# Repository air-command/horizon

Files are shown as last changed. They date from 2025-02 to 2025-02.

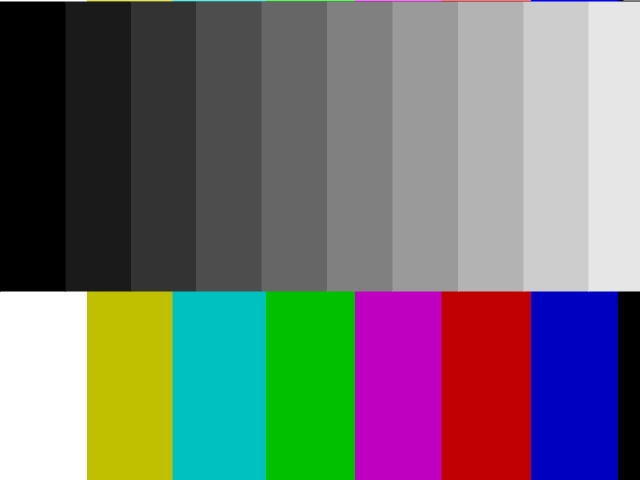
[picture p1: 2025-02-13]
01_Launcher/A5_Controller/rpi_190308/test.jpg

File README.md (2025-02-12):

# Horizon - 2 Stage Water Rocket
## Introduction
The files available in this repository are free of charge, but we would appreciate credit if you use these files in your projects. 
The files are provided as-is in the hope some may be used as a reference when working on your own projects. 

This is not a step-by-step guide how to build the Horizon rocket.
This repository is not an exhaustive breakdown of all the components in the Horizon project, it is simply a collection of files that we had used during the construction of the project.

## Navigating the data set
Components use Unit number / Assembly Number / Part Number labeling scheme.

Example: 03A2A3P6 expands to 03_Booster > A2_Deployment > A3_Camera_Pod > P6_Battery_808
Which refers to the 808 camera battery mount of the camera pod on top of the Booster. 

The **info.txt** files in any folder include general information about that assembly or part. 

## PLEASE NOTE
This repository will be actively updated over the coming weeks/months as we organize all the files.

## Construction Videos
The YouTube playlist with all the construction videos is available here:\
https://www.youtube.com/playlist?list=PL-zcDPSotX7pQ490T-lMMBW_i7fbfD8UH

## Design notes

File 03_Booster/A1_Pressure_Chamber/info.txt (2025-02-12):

Booster test pressure chamber
Inner liner + booster spacing jig cylinders: 85 gsm cloth single wrap -1060x290mm - Needed 2 pumps

2 layers of 200gsm carbon fiber - 5 pumps including peel ply. 

3" light sleeve over top for spacing jig cylinders. 

1 - pump for internal coat of pressure chamber.

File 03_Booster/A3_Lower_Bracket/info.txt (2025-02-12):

The lower bracket joins the booster segments together at the bottom of the booster. There are 3 of them. 
The bracket is glued to the bracket pads with 24hour Araldite, and then reinforced - See P3

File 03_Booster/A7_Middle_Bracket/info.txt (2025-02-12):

The middle bracket holds the 3 booster segments together, and supports the staging mechanism. The entire booster is held down by the middle bracket.

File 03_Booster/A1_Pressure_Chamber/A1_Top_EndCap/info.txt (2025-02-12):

--------------
Top Endcap

210mm long 2.5" medium carbon sleeve.
4 x 85 gsm fiberglass plain weave gores
1 x 40mm wide single wrap of 85 gsm fiberglass for the base.

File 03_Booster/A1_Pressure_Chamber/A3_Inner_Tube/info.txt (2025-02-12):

P2 - 85gsm fiberglass single wrap - applied as 2 separate pieces, overlapped in the middle. 
P3 - 200gsm carbon fiber plain weave = 2 wraps - single piece
P4 - peel ply on the outside. - applied as 2 separate pieces, overlapped in the middle. 

- thin masking tape 
- baking paper - split in half, 4.8m long - each half can make 1 tube. 
- west systems epoxy 3-4 pumps for fiberglass inner liner
- west systems epoxy 10-12 pumps for carbon wrap including peel ply. 

After curing and removing from mandrel. 
- inside is coated 2x with west systems - 3 pumps per coat. 

NOTE: DO NOT EXTEND TAPE into the joint between endcaps.

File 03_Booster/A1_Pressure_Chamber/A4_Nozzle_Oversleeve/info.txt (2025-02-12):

This nozzle oversleve is made from 42mm aluminium bar. It is a fix for the nozzle leak.

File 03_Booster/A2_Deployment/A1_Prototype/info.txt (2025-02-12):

This was a prototype flown on Horizon Part #33

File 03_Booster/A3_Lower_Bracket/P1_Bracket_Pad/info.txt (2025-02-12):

The bracket pad attaches the bracket to the pressure chamber. It is made from a curved section made from carbon fiber. 
Several of these curved sections are made from a larger tube. This tube is made from 850x270mm 200gsm carbon fiber plain weave cloth. This is 3 wraps over a pressure chamber mandrel. Note that the mandrel for this is the actual pressure chamber, rather than the mandrel used to make the pressure chamber. This carbon fiber tube is topped with 1 wrap of 85gsm 300x270mm plain weave fiberglass for a nicer finish. It took 2 pumps to fully wet out.

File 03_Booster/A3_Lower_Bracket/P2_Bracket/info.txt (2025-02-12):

The bracket joins the two bracket pads together. It is made from 3mm CF plate from Hobby King. 
Each bracket is made from 60x130mm rectangle.

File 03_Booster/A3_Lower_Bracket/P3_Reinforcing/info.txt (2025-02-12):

After the bracket is glued to the bracket pads with 24hour Araldite, each joint is reinforced from the outside with 10 layers of 85gsm fiberglass cloth. Each layer alternates in orientation 0-90 and 45-45.

Here are the layers cut out from the FG cloth:
45x60 x3
40x60 x3
35x60 x2
30x60 x2

The inside corner is reinforced with 6 alternating 0-90 and 45-45 layers of 85gsm cloth all the same size 60x35mm

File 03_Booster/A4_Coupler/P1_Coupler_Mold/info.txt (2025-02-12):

5 layers top and bottom
3 perimeter layers
10% infill
0.25mm layer height 
PLA
default printing speed: 4800mm/min

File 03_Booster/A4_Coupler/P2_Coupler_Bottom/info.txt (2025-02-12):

The top and bottom couplers are made together in one piece and then cut. 
1mm wall thickness.
3 wraps of 200gsm plain weave CF 770 x 70mm
3 wraps of 85gsm plain weave Fiberglass 700 x 70mm
Uses 1 pump of epoxy
Bottom coupler is 40mm tall
Top coupler is 25mm tall.

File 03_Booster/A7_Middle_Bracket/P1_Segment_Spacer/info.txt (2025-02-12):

The segment spacer helps align the middle brackets during construction. The spacer also is used during the assembly of the entire booster to get the correct inter-segment spacing. 

3D Printer settings:

5 layers top and bottom
3 perimeter layers
10% infill
0.25mm layer height 
PLA
default printing speed: 3000mm/min

3 hours to print

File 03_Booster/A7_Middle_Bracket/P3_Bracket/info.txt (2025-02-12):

There are 6 brackets made from 3mm carbon fiber plate. Each bracket is 50mm wide, 140mm long on the outside and 110mm on the inside.

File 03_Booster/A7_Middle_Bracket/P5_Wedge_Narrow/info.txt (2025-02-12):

This is used to help force the reinforcing cloth into shape in the narrow spaces between the brackets.

PLA+ Black
3 top and bottom layers
0.25 layer height
speed 4800
3 perimeter layers
10% infill

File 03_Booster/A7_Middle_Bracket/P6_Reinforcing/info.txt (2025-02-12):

Narrow wedge reinforcing:
layer 1: 0-90 200gsm Carbon fiber 45 x 130mm
layer 2: 45-45 200gsm Carbon fiber 45 x 130mm
layer 3: 0-90 200gsm Carbon fiber 45 x 130mm
layer 4: 45-45 200gsm Carbon fiber 45 x 130mm
top layer: 0-90 85gsm fiberlgass 45 x 130mm
baking paper on top and pressed down with the 3D printed Wedge
This is repeated 3 times

Wide wedge reinforcing:
layer 1: 0-90 200gsm Carbon fiber 50 x 130mm
layer 2: 45-45 200gsm Carbon fiber 50 x 130mm
layer 3: 0-90 200gsm Carbon fiber 50 x 130mm
layer 4: 45-45 200gsm Carbon fiber 50 x 130mm
top layer: 0-90 85gsm fiberlgass 50 x 130mm
baking paper on top and pressed down with the 3D printed Wedge
This is repeated 3 times

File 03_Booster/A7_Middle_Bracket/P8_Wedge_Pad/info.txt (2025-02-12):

This is used to help force the reinforcing cloth into shape between the bracket and the curved pad

PLA+ White
3 top and bottom layers
0.25 layer height
speed 4800
3 perimeter layers
10% infill

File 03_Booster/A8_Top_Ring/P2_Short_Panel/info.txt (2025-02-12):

The top ring is made from 3 short and 3 long panels. 
The short panel is 136mm x 67mm
The long panel is 147mm x 67mm
Each panel's edges are angled where they meet together.

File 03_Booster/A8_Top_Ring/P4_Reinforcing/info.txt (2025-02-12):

The reinforcing on the outside and inside of each joint of the ring is the same. 
The following layers are used. The shortest is on the inside and the longest is on the outside.

layer 1: 20 x 80mm - 45-45 CF
layer 2: 30 x 80mm - 0-90 CF
layer 3: 30 x 80mm - 45-45 CF
layer 4: 40 x 80mm - 0-90 CF
layer 5: 50 x 80mm - 45-45 CF
layer 6: 55 x 80mm - 0-90 85 gsm glass

These are all layed up on a piece of baking paper with the outside first
These are then applied to both the inside and outside and compressed together between the P1_Wedges until cured.

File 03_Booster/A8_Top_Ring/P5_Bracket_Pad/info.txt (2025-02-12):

This is a pad that attaches the top ring to the booster segment. It is made from a tube whose inside diameter is the outside diameter of the booster segment. The pad itself is 77mm long and 55mm wide.

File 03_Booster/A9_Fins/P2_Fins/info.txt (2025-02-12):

The fins are made from 3mm plywood.
Each side has:
Lowest level: 
bias cut 200gsm glass
straight cut CF sheet
bias cut CF sheet
straight cut 85gsm glass. 

Size of plywood was 23cm x 36cm
Size of cloth: 24cm x 36cm

Each side took 2 pumps of epoxy

Fins were sandwitched between two plates of glass.

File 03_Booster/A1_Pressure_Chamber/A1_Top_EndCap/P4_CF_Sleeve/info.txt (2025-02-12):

210mm long 2.5" Medium Carbon fiber sleeve

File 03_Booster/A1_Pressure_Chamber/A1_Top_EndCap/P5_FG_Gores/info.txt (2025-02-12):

4 x 85gsm plain weave fiberglass, bias cut - shape based on template.

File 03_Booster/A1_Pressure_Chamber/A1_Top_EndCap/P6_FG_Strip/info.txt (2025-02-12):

2 wraps of 40mm wide 85gsm fiberglass cloth. 
This is wrapped around the base after the gores have been applied to the sleeve.

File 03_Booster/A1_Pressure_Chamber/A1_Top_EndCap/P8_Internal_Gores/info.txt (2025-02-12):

21 x 85gsm gores applied to the inside of the endcap. The pattern is straight cut (not bias) using the cardboard pattern. 
The gores are applied in 3 layers with 7 gores per layer. Each layer is offset by 1/3 the width of a gore.

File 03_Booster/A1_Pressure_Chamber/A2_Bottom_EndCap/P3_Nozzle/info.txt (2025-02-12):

Nozzle is machined from aluminium.
Internal diameter: 19.45mm
Extternal diameter: 22.75mm
Length: 25mm

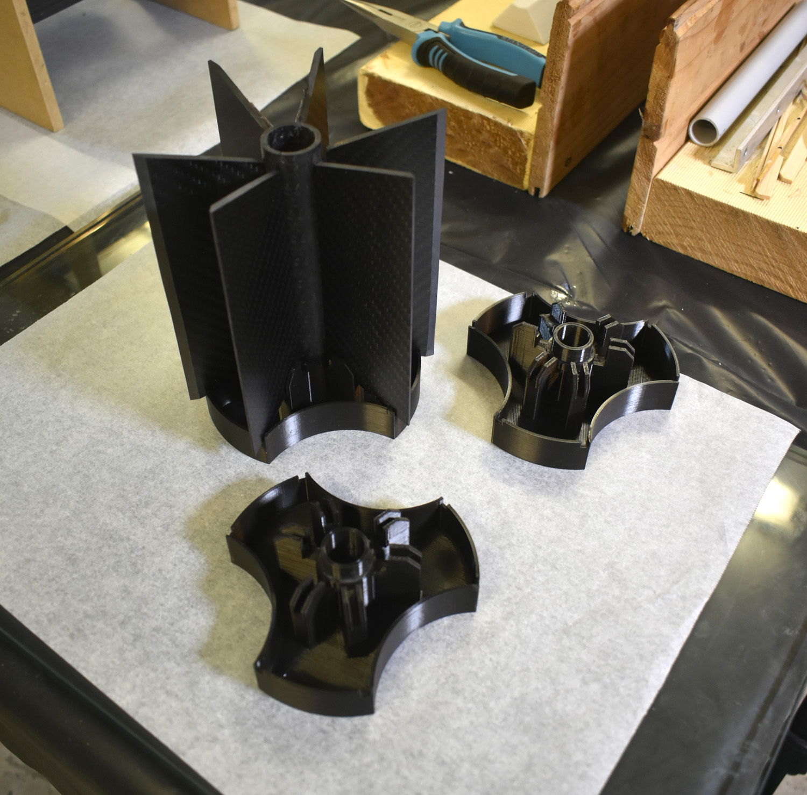
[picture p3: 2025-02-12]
03_Booster/A7_Middle_Bracket/photos/A7_Bracket2.jpg

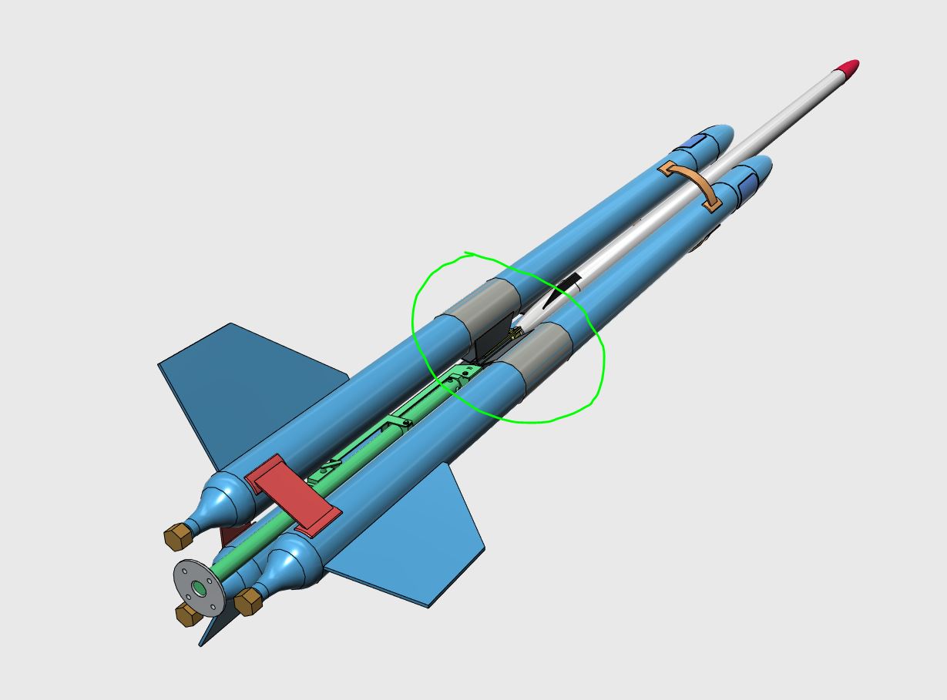
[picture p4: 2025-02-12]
03_Booster/A7_Middle_Bracket/photos/middle_bracket.JPG

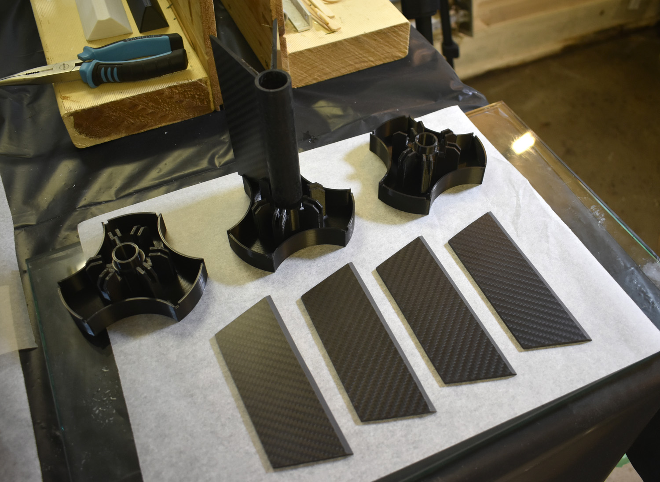
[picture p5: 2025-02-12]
03_Booster/A7_Middle_Bracket/photos/A7_Bracket1.jpg

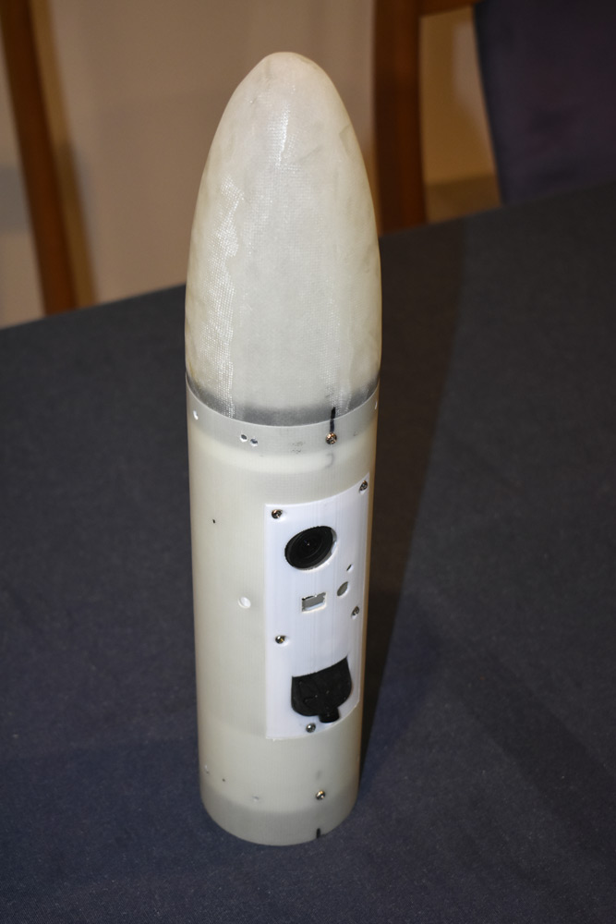
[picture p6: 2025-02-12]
03_Booster/A2_Deployment/A2_Main_Deploy/photos/CameraPod1.jpg

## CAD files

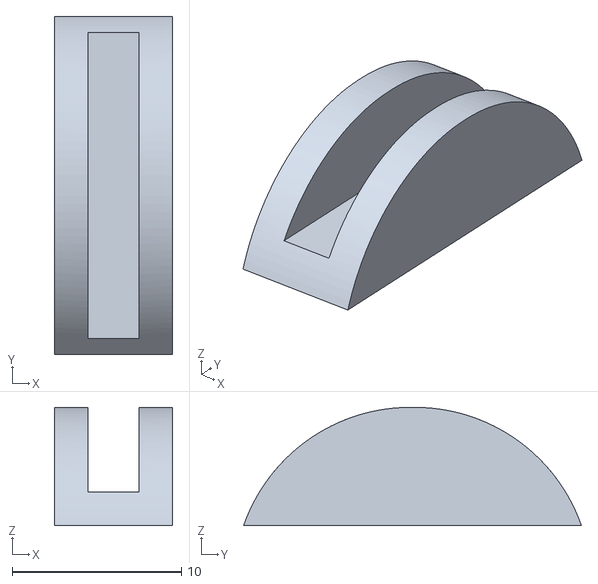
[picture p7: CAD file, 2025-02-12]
03_Booster/A10_ParachuteHarness/P1_ShockCord_Mount.stl
7.00 x 20.0 x 7.00

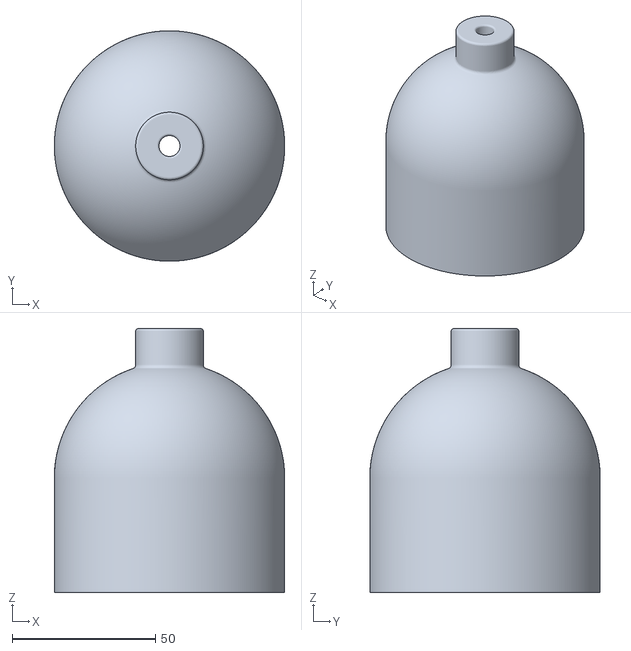
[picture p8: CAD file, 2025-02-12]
03_Booster/A1_Pressure_Chamber/A1_Top_EndCap/P1_Top_EndCap_Mold/P1_Top_EndCap_Mold_2.stl
80.4 x 80.4 x 92.1

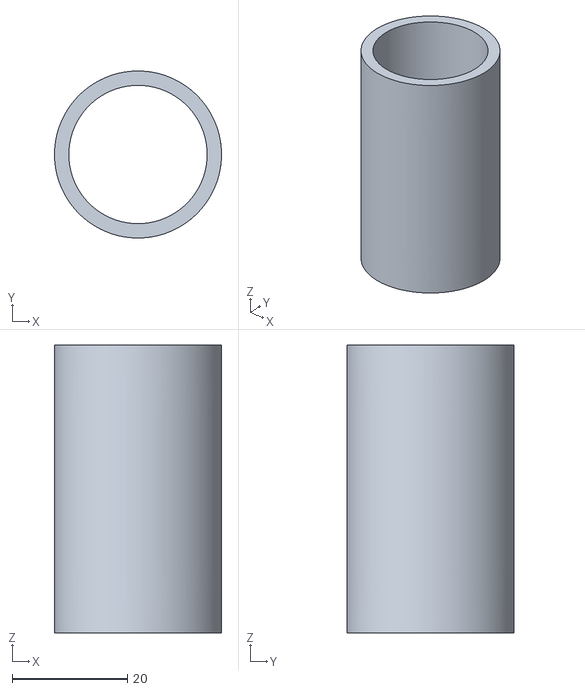
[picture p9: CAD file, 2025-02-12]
03_Booster/A1_Pressure_Chamber/A1_Top_EndCap/P2_Top_EndCap_Ring/P2_Top_EndCap_Ring.stl
29.0 x 29.0 x 50.0

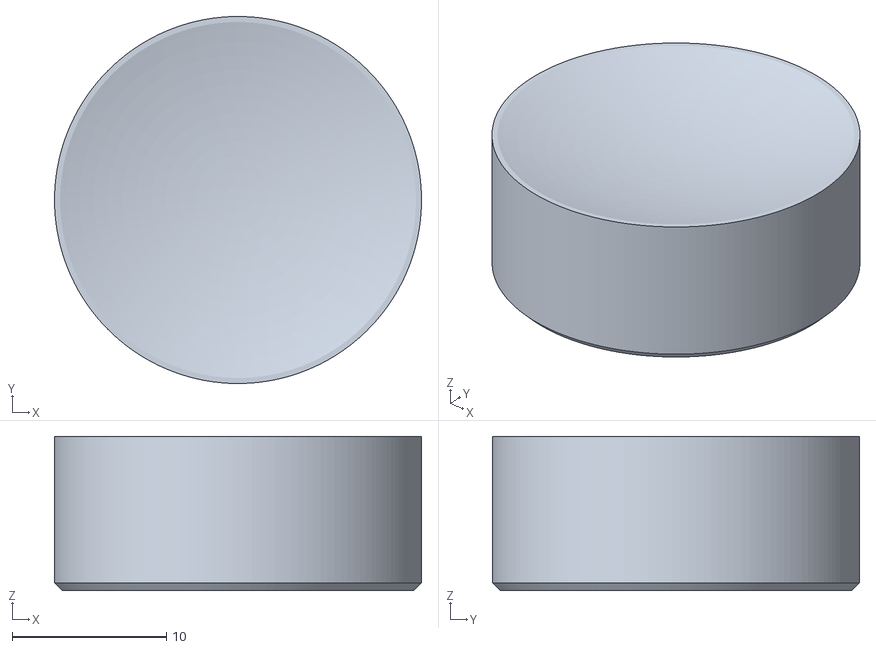
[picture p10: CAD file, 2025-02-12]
03_Booster/A1_Pressure_Chamber/A1_Top_EndCap/P3_Top_EndCap_Plug/P3_Top_EndCap_Plug.stl
23.8 x 23.8 x 10.0

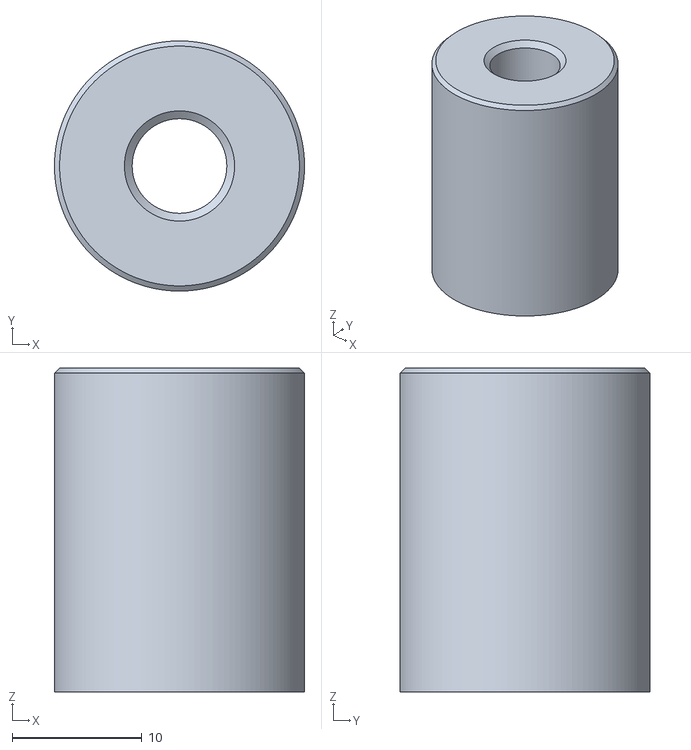
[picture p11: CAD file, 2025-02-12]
03_Booster/A1_Pressure_Chamber/A2_Bottom_EndCap/P1_NozzleMeasure/P1_NozzleMeasure.stl
19.3 x 19.3 x 25.0

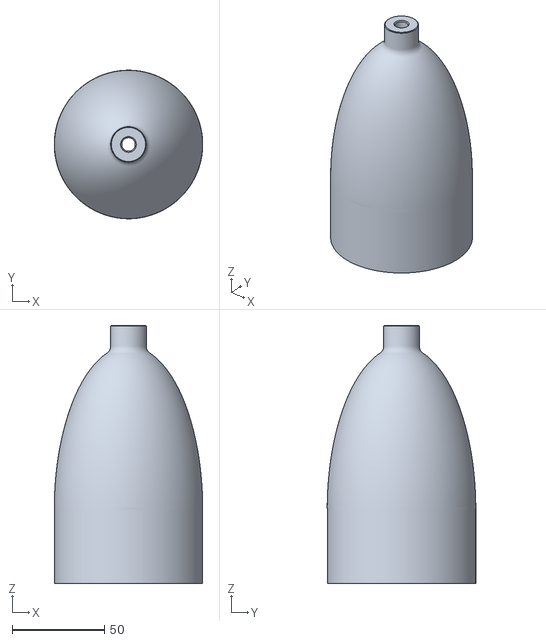
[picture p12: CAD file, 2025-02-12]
03_Booster/A1_Pressure_Chamber/A2_Bottom_EndCap/P2_Bottom_Endcap_Mold/P2_Bottom_Endcap_Mold_2.stl
80.4 x 80.5 x 139.7

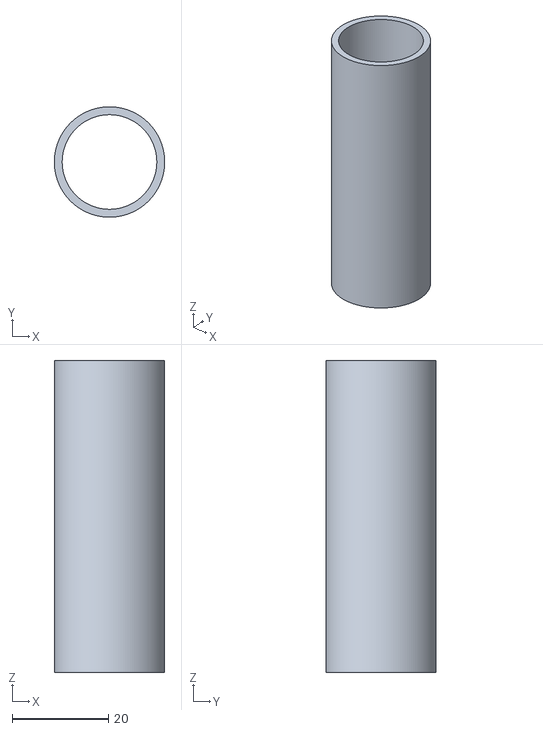
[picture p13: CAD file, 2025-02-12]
03_Booster/A1_Pressure_Chamber/A2_Bottom_EndCap/P4_Nozzle_Extension/P4_Nozzle_Extension_Long.stl
23.0 x 23.0 x 65.0

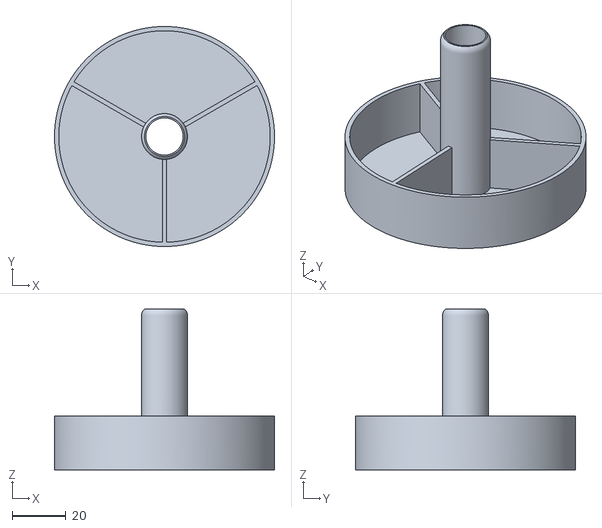
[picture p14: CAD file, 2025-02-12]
03_Booster/A1_Pressure_Chamber/A2_Bottom_EndCap/P9_Nozzle_Alignment_Jig/P9_Nozzle_Alignment_Jig.stl
81.5 x 81.5 x 59.6

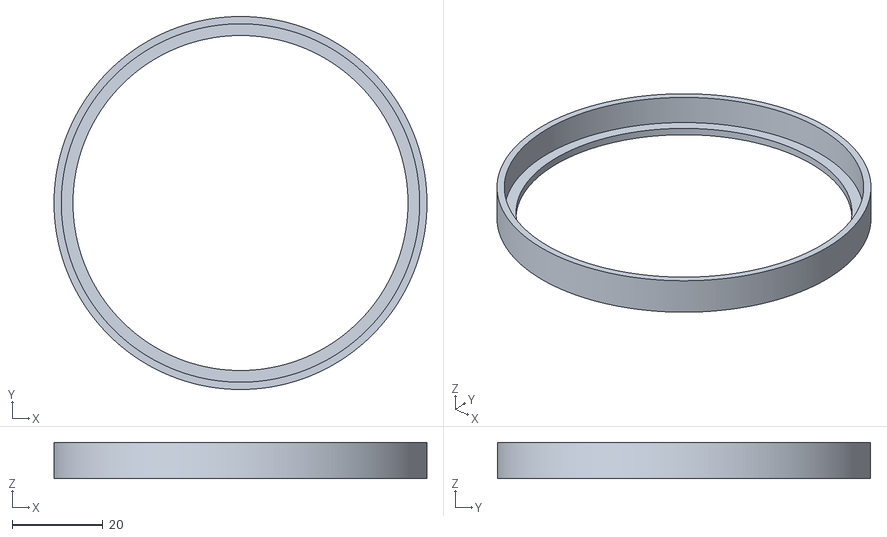
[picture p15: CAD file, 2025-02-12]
03_Booster/A2_Deployment/A1_Prototype/P1_TestRing/P1_TestRing.stl
82.4 x 82.4 x 8.00

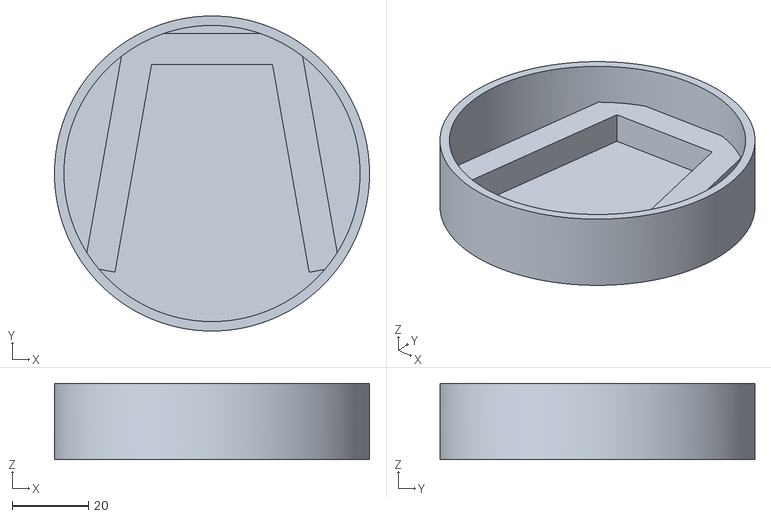
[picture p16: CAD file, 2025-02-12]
03_Booster/A2_Deployment/A1_Prototype/P3_Top_Bulkhead/P3_Top_Bulkhead_2.stl
82.4 x 82.4 x 20.0

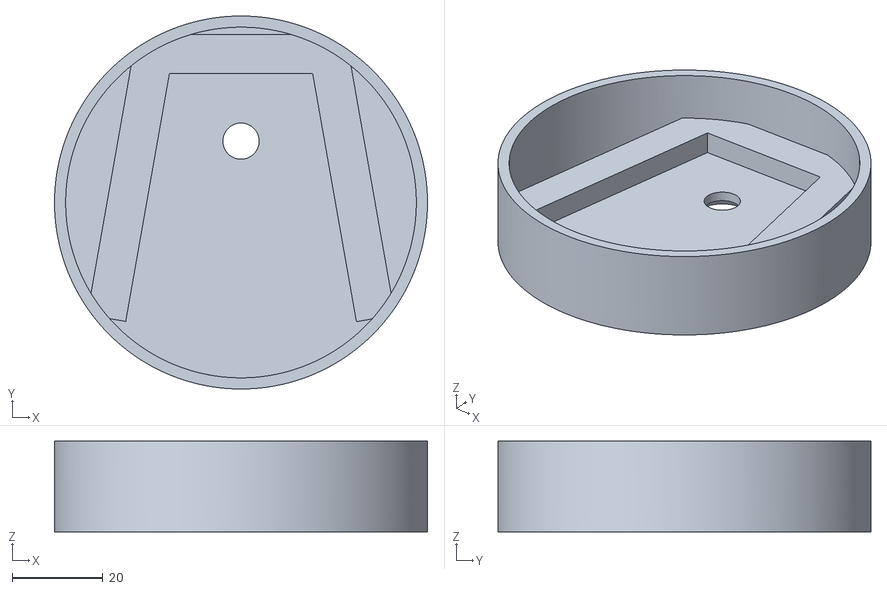
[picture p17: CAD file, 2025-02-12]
03_Booster/A2_Deployment/A1_Prototype/P4_Bottom_Bulkhead/P4_Bottom_Bulhead.stl
82.4 x 82.4 x 20.0

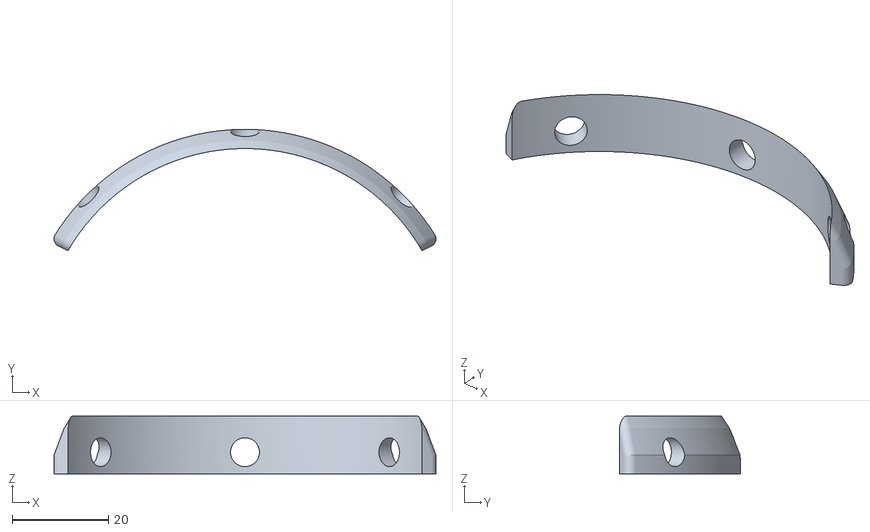
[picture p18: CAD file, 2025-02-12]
03_Booster/A2_Deployment/A2_Main_Deploy/P10_Deflector/P10_Deflector.stl
79.4 x 25.2 x 12.0

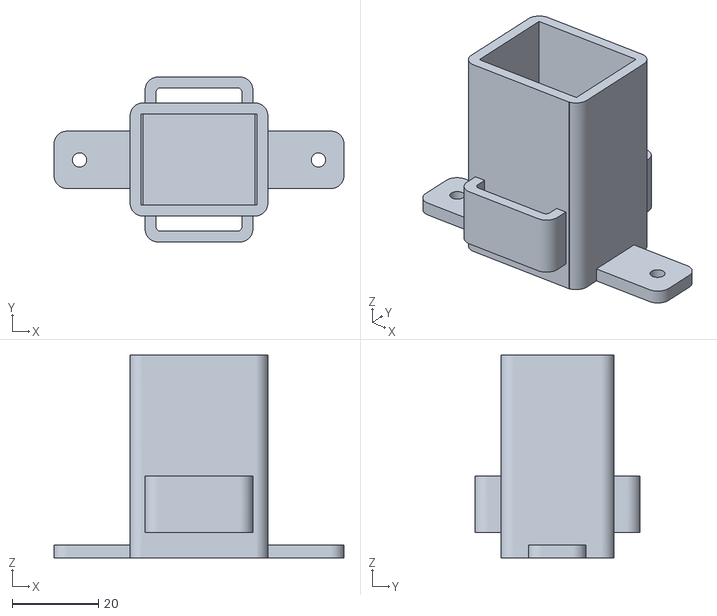
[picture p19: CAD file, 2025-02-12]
03_Booster/A2_Deployment/A2_Main_Deploy/P11_Battery_Holder_C/P11_Battery_Holder_C.stl
67.3 x 38.2 x 47.0

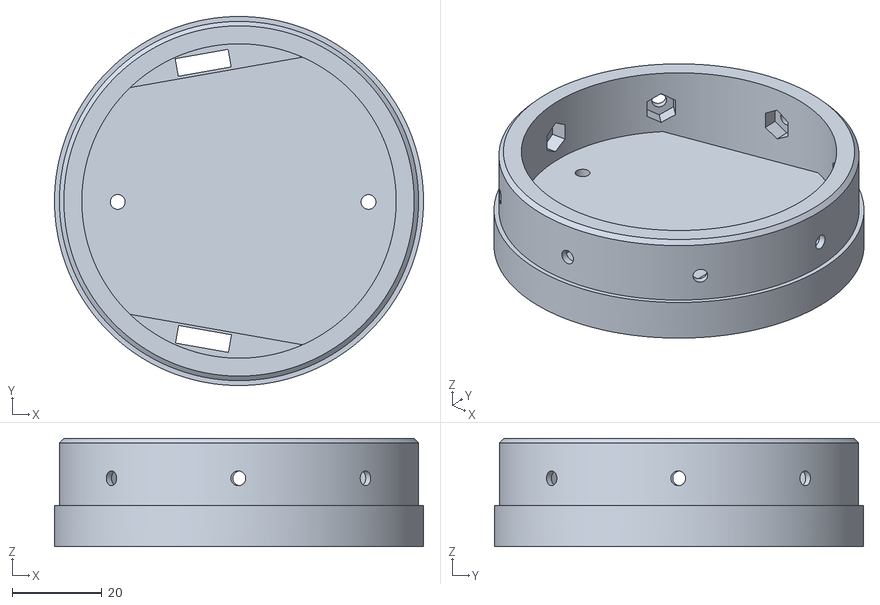
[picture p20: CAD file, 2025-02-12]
03_Booster/A2_Deployment/A2_Main_Deploy/P1_Top_Bulkhead/P1_Top_Bulkhead_4.stl
82.4 x 82.4 x 24.2

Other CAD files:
03_Booster/A2_Deployment/A2_Main_Deploy/P2_Bottom_Bulkhead/P2_Bottom_Bulkhead.stl
03_Booster/A2_Deployment/A2_Main_Deploy/P3_Body/P3_Body.stl
03_Booster/A2_Deployment/A2_Main_Deploy/P3_Body_Back/P3_Body_Back.stl
03_Booster/A2_Deployment/A2_Main_Deploy/P4_Body_Servo/P4_Body_Servo.stl
03_Booster/A1_Pressure_Chamber/A1_Top_EndCap/P1_Top_EndCap_Mold/P1_Top_EndCap_Mold.stl
03_Booster/A1_Pressure_Chamber/A1_Top_EndCap/archive/Top endcap ring test.stl
03_Booster/A1_Pressure_Chamber/A2_Bottom_EndCap/P2_Bottom_Endcap_Mold/P2_Bottom_Endcap_Mold.stl
03_Booster/A1_Pressure_Chamber/A2_Bottom_EndCap/P4_Nozzle_Extension/P4_Nozzle_Extension.stl
03_Booster/A2_Deployment/A1_Prototype/P3_Top_Bulkhead/P3_Top_Bulkhead_3.stl
03_Booster/A2_Deployment/A2_Main_Deploy/P3_Body/P3_Body_servo.stl
03_Booster/A2_Deployment/A2_Main_Deploy/P4_Body_Servo/switch_holder.stl
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

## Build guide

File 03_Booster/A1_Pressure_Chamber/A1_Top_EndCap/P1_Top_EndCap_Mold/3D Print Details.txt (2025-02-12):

Top Endcap Mold
Supports: No
Additions: No
Layer Height: 0.25
Bottom Layers: 6
Top Layers: 6
Perimeters: 4
Infill: 10%

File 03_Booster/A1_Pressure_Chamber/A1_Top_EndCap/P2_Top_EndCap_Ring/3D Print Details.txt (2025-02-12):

Top Endcap Ring
Supports: No
Additions: skirt - 2 layers 
Layer Height: 0.25
Bottom Layers: 3
Top Layers: 3
Perimeters: 4
Infill: 100%

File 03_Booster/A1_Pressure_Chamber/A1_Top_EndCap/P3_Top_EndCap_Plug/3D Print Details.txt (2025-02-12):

Top Endcap Plug
Supports: No
Additions: No
Layer Height: 0.25
Bottom Layers: 3
Top Layers: 3
Perimeters: 2
Infill: 100%

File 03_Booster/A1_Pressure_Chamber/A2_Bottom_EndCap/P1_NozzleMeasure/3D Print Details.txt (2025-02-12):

P1_NozzleMeasure - Bottom Endcap Measure
Supports: No
Additions: No
Layer Height: 0.25
Bottom Layers: 3
Top Layers: 3
Perimeters: 4
Infill: 15%

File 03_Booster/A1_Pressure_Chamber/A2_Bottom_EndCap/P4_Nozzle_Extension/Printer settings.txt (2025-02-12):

P4_Nozzle_Extension
Supports: No
Additions: No
Layer Height: 0.25
Bottom Layers: 3
Top Layers: 3
Perimeters: 4
Infill: 10% - though it ends up being solid

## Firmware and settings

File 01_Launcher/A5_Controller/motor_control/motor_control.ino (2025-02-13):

// Horizon Launcher - Motor controller
// George Katz 1st January 2019

//#include <Servo.h>

// =================== State Definitions ================================

const int STATE_FILL_START      = 0;
const int STATE_FILL_CLOSED     = 1;
const int STATE_FILL_CLOSING    = 2;
const int STATE_FILL_OPEN       = 3;
const int STATE_FILL_OPENING    = 4;

const int STATE_VENT_START      = 0;
const int STATE_VENT_CLOSED     = 1;
const int STATE_VENT_CLOSING    = 2;
const int STATE_VENT_OPEN       = 3;
const int STATE_VENT_OPENING    = 4;

const int STATUS_LED_OFF		    = 0;
const int STATUS_LED_ON			    = 1;
const int STATUS_LED_FLASH		  = 2;

// =================== Pin definitions ================================
const int FILL_MOTOR_OPEN       = 21;
const int FILL_MOTOR_CLOSE      = 20;
const int VENT_MOTOR_OPEN       = 19;
const int VENT_MOTOR_CLOSE      = 18;

const int LAUNCH_SERVO          = 9;

const int FILL_LIMIT_OPEN       = 15;
const int FILL_LIMIT_CLOSED     = 14;
const int VENT_LIMIT_OPEN       = 16;
const int VENT_LIMIT_CLOSED     = 10;

const int VENT_OPEN_BTN         = 6;
const int FILL_OPEN_BTN         = 7;
const int LAUNCH_BTN            = 8;

const int VENT_OPEN_RPI         = 1;
const int FILL_OPEN_RPI         = 0;
const int LAUNCH_RPI            = 2;

const int VENT_LED				      = 3;
const int FILL_LED				      = 4;
const int LAUNCH_LED			      = 5;

// ==================== Variables ====================================
//Servo launchServo;  // create servo object to control a servo

int launchState               = 0;        // 
unsigned long previousMillis  = 0;        // 
const long interval           = 500;      // 

bool flasher                   = false;					// This value continuously toggles on and off to flash LEDs
const long flashPeriod         = 50;        // period at which to flash LEDs (milliseconds)
unsigned long previousMillis2  = 0;        // 

int fillLimitOpen   = 0;              // Limit Switches
int fillLimitClosed = 0;
int ventLimitOpen   = 0;
int ventLimitClosed = 0;

int fillBtn         = 0;              // Manual Switches
int ventBtn         = 0;
int launchBtn       = 0;

int fill_state      = STATE_FILL_START;   // state of valve motor
int vent_state      = STATE_VENT_START;

int fillLEDState 	  = STATUS_LED_OFF;	    // Status LEDs
int ventLEDState 	  = STATUS_LED_OFF;	
int launchLEDState 	= STATUS_LED_OFF;	

//int servoStartPos   = 60;
//int servoEndPos     = 100;

void setup() {
  pinMode(FILL_MOTOR_OPEN,OUTPUT);          // 
  pinMode(FILL_MOTOR_CLOSE,OUTPUT);         // 
  pinMode(VENT_MOTOR_OPEN,OUTPUT);          // 
  pinMode(VENT_MOTOR_CLOSE,OUTPUT);         // 
  pinMode(LAUNCH_SERVO,OUTPUT);             // 
  pinMode(FILL_LIMIT_OPEN,INPUT_PULLUP);    // 
  pinMode(FILL_LIMIT_CLOSED,INPUT_PULLUP);  // 
  pinMode(VENT_LIMIT_OPEN,INPUT_PULLUP);    // 
  pinMode(VENT_LIMIT_CLOSED,INPUT_PULLUP);  // 
  pinMode(VENT_OPEN_BTN,INPUT_PULLUP);      // 
  pinMode(FILL_OPEN_BTN,INPUT_PULLUP);      // 
  pinMode(LAUNCH_BTN,INPUT_PULLUP);         // 
  pinMode(VENT_OPEN_RPI,INPUT);             // 
  pinMode(FILL_OPEN_RPI,INPUT);             // 
  pinMode(LAUNCH_RPI,INPUT);                // 
  pinMode(VENT_LED,OUTPUT);             	// 
  pinMode(FILL_LED,OUTPUT);             	// 
  pinMode(LAUNCH_LED,OUTPUT);             	// 

  Serial.begin(9600); //This pipes to the serial monitor

  setFillState(STATE_FILL_START);
  setVentState(STATE_VENT_START);

  digitalWrite(LAUNCH_SERVO,  LOW);

//  launchServo.attach(LAUNCH_SERVO);
//  launchServo.write(servoStartPos);

}


void setFillState(int newState) {
  fill_state = newState;
 
  switch(fill_state){
    case STATE_FILL_START:
      digitalWrite(FILL_MOTOR_OPEN,  LOW);    // motor off
      digitalWrite(FILL_MOTOR_CLOSE, LOW);
    break;
    
    case STATE_FILL_CLOSED:
      digitalWrite(FILL_MOTOR_OPEN,  LOW);    // motor off
      digitalWrite(FILL_MOTOR_CLOSE, LOW);
	    fillLEDState 	= STATUS_LED_OFF;	
    break;
    
    case STATE_FILL_CLOSING:
      digitalWrite(FILL_MOTOR_OPEN,  LOW);    // motor moving to close valve
      digitalWrite(FILL_MOTOR_CLOSE, HIGH);
	    fillLEDState 	= STATUS_LED_FLASH;	
    break;
    
    case STATE_FILL_OPEN:
      digitalWrite(FILL_MOTOR_OPEN,  LOW);    // motor off
      digitalWrite(FILL_MOTOR_CLOSE, LOW);    
	    fillLEDState 	= STATUS_LED_ON;	
    break;
    
    case STATE_FILL_OPENING:
      digitalWrite(FILL_MOTOR_OPEN,  HIGH);   // motor moving to open valve
      digitalWrite(FILL_MOTOR_CLOSE, LOW);
	    fillLEDState 	= STATUS_LED_FLASH;	
    break;
  }

  if(fillLEDState == STATUS_LED_OFF) {
    digitalWrite(FILL_LED,  HIGH);
  } else if(fillLEDState == STATUS_LED_ON) {
    digitalWrite(FILL_LED,  LOW);
  }

}


void setVentState(int newState) {
  vent_state = newState;
 
  switch(vent_state){
    case STATE_VENT_START:
      digitalWrite(VENT_MOTOR_OPEN,  LOW);    // motor off
      digitalWrite(VENT_MOTOR_CLOSE, LOW);
    break;
    
    case STATE_VENT_CLOSED:
      digitalWrite(VENT_MOTOR_OPEN,  LOW);    // motor off
      digitalWrite(VENT_MOTOR_CLOSE, LOW);
	    ventLEDState 	= STATUS_LED_OFF;	
    break;
    
    case STATE_VENT_CLOSING:
      digitalWrite(VENT_MOTOR_OPEN,  LOW);    // motor moving to close valve
      digitalWrite(VENT_MOTOR_CLOSE, HIGH);
	    ventLEDState 	= STATUS_LED_FLASH;	
    break;
    
    case STATE_VENT_OPEN:
      digitalWrite(VENT_MOTOR_OPEN,  LOW);    // motor off
      digitalWrite(VENT_MOTOR_CLOSE, LOW);    
	    ventLEDState 	= STATUS_LED_ON;	
    break;
    
    case STATE_VENT_OPENING:
      digitalWrite(VENT_MOTOR_OPEN,  HIGH);   // motor moving to open valve
      digitalWrite(VENT_MOTOR_CLOSE, LOW);
	    ventLEDState 	= STATUS_LED_FLASH;	
    break;
  }

  if(ventLEDState == STATUS_LED_OFF) {
    digitalWrite(VENT_LED,  HIGH);
  } else if(ventLEDState == STATUS_LED_ON) {
    digitalWrite(VENT_LED,  LOW);
  }
}


void loop() {
  //read limit switches
  fillLimitOpen   = !digitalRead(FILL_LIMIT_OPEN);   // Fill motor in fully open position    - air flowing in
  fillLimitClosed = !digitalRead(FILL_LIMIT_CLOSED); // Fill motor in fully closed position  - no air flowing in
  ventLimitOpen   = !digitalRead(VENT_LIMIT_OPEN);
  ventLimitClosed = !digitalRead(VENT_LIMIT_CLOSED);

  // read manual override switches
  // We combine these with the requests coming in from the Raspberry Pi.
  fillBtn         = digitalRead(FILL_OPEN_BTN) && digitalRead(FILL_OPEN_RPI);
  ventBtn         = digitalRead(VENT_OPEN_BTN) && digitalRead(VENT_OPEN_RPI);
  launchBtn       = digitalRead(LAUNCH_BTN)    && digitalRead(LAUNCH_RPI);

  // ========== Fill State Machine =================
  switch(fill_state){
    case STATE_FILL_START:
      if(fillLimitClosed) {   // already at limnit
        setFillState(STATE_FILL_CLOSED);
      } else {
        setFillState(STATE_FILL_CLOSING);
      }
    break;
    
    case STATE_FILL_CLOSED:
      if(fillBtn) {
        setFillState(STATE_FILL_OPENING);
      }
    break;
    
    case STATE_FILL_CLOSING:
      if(fillLimitClosed) {   // already at limnit
        setFillState(STATE_FILL_CLOSED);
      }
      if(fillBtn && !fillLimitOpen) {
        setFillState(STATE_FILL_OPENING);
      }
    break;
    
    case STATE_FILL_OPEN:
      if(!fillBtn) {
        setFillState(STATE_FILL_CLOSING);
      }
    break;
    
    case STATE_FILL_OPENING:
      if(fillLimitOpen) {   // already at limnit
        setFillState(STATE_FILL_OPEN);
      }
      if(!fillBtn && !fillLimitClosed) {
        setFillState(STATE_FILL_CLOSING);
      }
    break;
  }

  // ========== Vent State Machine =================

  switch(vent_state){
    case STATE_VENT_START:
      if(ventLimitClosed) {   // already at limnit
        setVentState(STATE_VENT_CLOSED);
      } else {
        setVentState(STATE_VENT_CLOSING);
      }
    break;
    
    case STATE_VENT_CLOSED:
      if(ventBtn) {
        setVentState(STATE_VENT_OPENING);
      }
    break;
    
    case STATE_VENT_CLOSING:
      if(ventLimitClosed) {   // already at limnit
        setVentState(STATE_VENT_CLOSED);
      }
      if(ventBtn && !ventLimitOpen) {
        setVentState(STATE_VENT_OPENING);
      }
    break;
    
    case STATE_VENT_OPEN:
      if(!ventBtn) {
        setVentState(STATE_VENT_CLOSING);
      }
    break;
    
    case STATE_VENT_OPENING:
      if(ventLimitOpen) {   // already at limnit
        setVentState(STATE_VENT_OPEN);
      }
      if(!ventBtn && !ventLimitClosed) {
        setVentState(STATE_VENT_CLOSING);
      }
    break;
  }

  if(!launchBtn && !launchState) {
    launchState = 1;
//    launchServo.write(servoEndPos);
    digitalWrite(LAUNCH_SERVO,  HIGH);
    digitalWrite(LAUNCH_LED,  HIGH);
    previousMillis = millis();
  }

  unsigned long currentMillis = millis();

  if (currentMillis - previousMillis >= interval && launchState) {
    previousMillis = currentMillis;
//    launchServo.write(servoStartPos);
    digitalWrite(LAUNCH_SERVO,  LOW);
    digitalWrite(LAUNCH_LED,  LOW);
    launchState = 0;
  }

  //The following is used to flash the status LEDs when needed. 
  if (currentMillis - previousMillis2 >= flashPeriod) {
    previousMillis2 = currentMillis;
    flasher = !flasher;   //toggle
    if(fillLEDState == STATUS_LED_FLASH) {
      if(flasher) {
        digitalWrite(FILL_LED,  HIGH);
      } else {
        digitalWrite(FILL_LED,  LOW);    
      }
    }

    if(ventLEDState == STATUS_LED_FLASH) {
      if(flasher) {
        digitalWrite(VENT_LED,  HIGH);
      } else {
        digitalWrite(VENT_LED,  LOW);    
      }
    }

  }




}

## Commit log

2025-02-12 Booster info
    [GOPRO_HERO_3.stp, GoPro_Hero_3_Frame.A.7.stl, GoPro_Hero_3_Frame.A.7.stp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]
2025-02-12 Added CAD files for overall model
2025-02-12 Added flight data, raw and processed
    [Horizon_BoosterA_processed.csv, Horizon_BoosterB_processed.csv, Horizon_Sustainer.csv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]
2025-02-13 Added electronics files
    [pressure chamber.xls]
